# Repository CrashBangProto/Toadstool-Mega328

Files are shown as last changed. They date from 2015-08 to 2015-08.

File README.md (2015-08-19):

Toadstool Logo
#Toadstool-Mega328

**Toadstool Development Board - ATmega328P**

The Toadstool family is made up of breadboard-friendly prototyping boards that house a microcontroller, and modules called *Caps* that connect using a standard header.  The prototyping board is analagous to an Arduino/Launchpad and the Cap analagous to a shield/boosterpack.

This repository contains the schematics for the **Toadstool-Mega328** prototyping board, a breadboard-friendly PCB that houses the ATmega328P microcontroller (or other Atmel pin-compatible variants such as the ATmega8/48/88/168/328).

The boards were layed out using [KiCad](http://www.kicad-pcb.org) - KiCad is open source and awesome.

There are a number of other CrashBangProto respositories containing the schematics for other Toadstool boards and Caps, as well as sample code to get you up and running.

Visit the [Toadstool Webpages](http://www.crash-bang.com/projects/toadstool/) for more information on the project.

Toadstool Board

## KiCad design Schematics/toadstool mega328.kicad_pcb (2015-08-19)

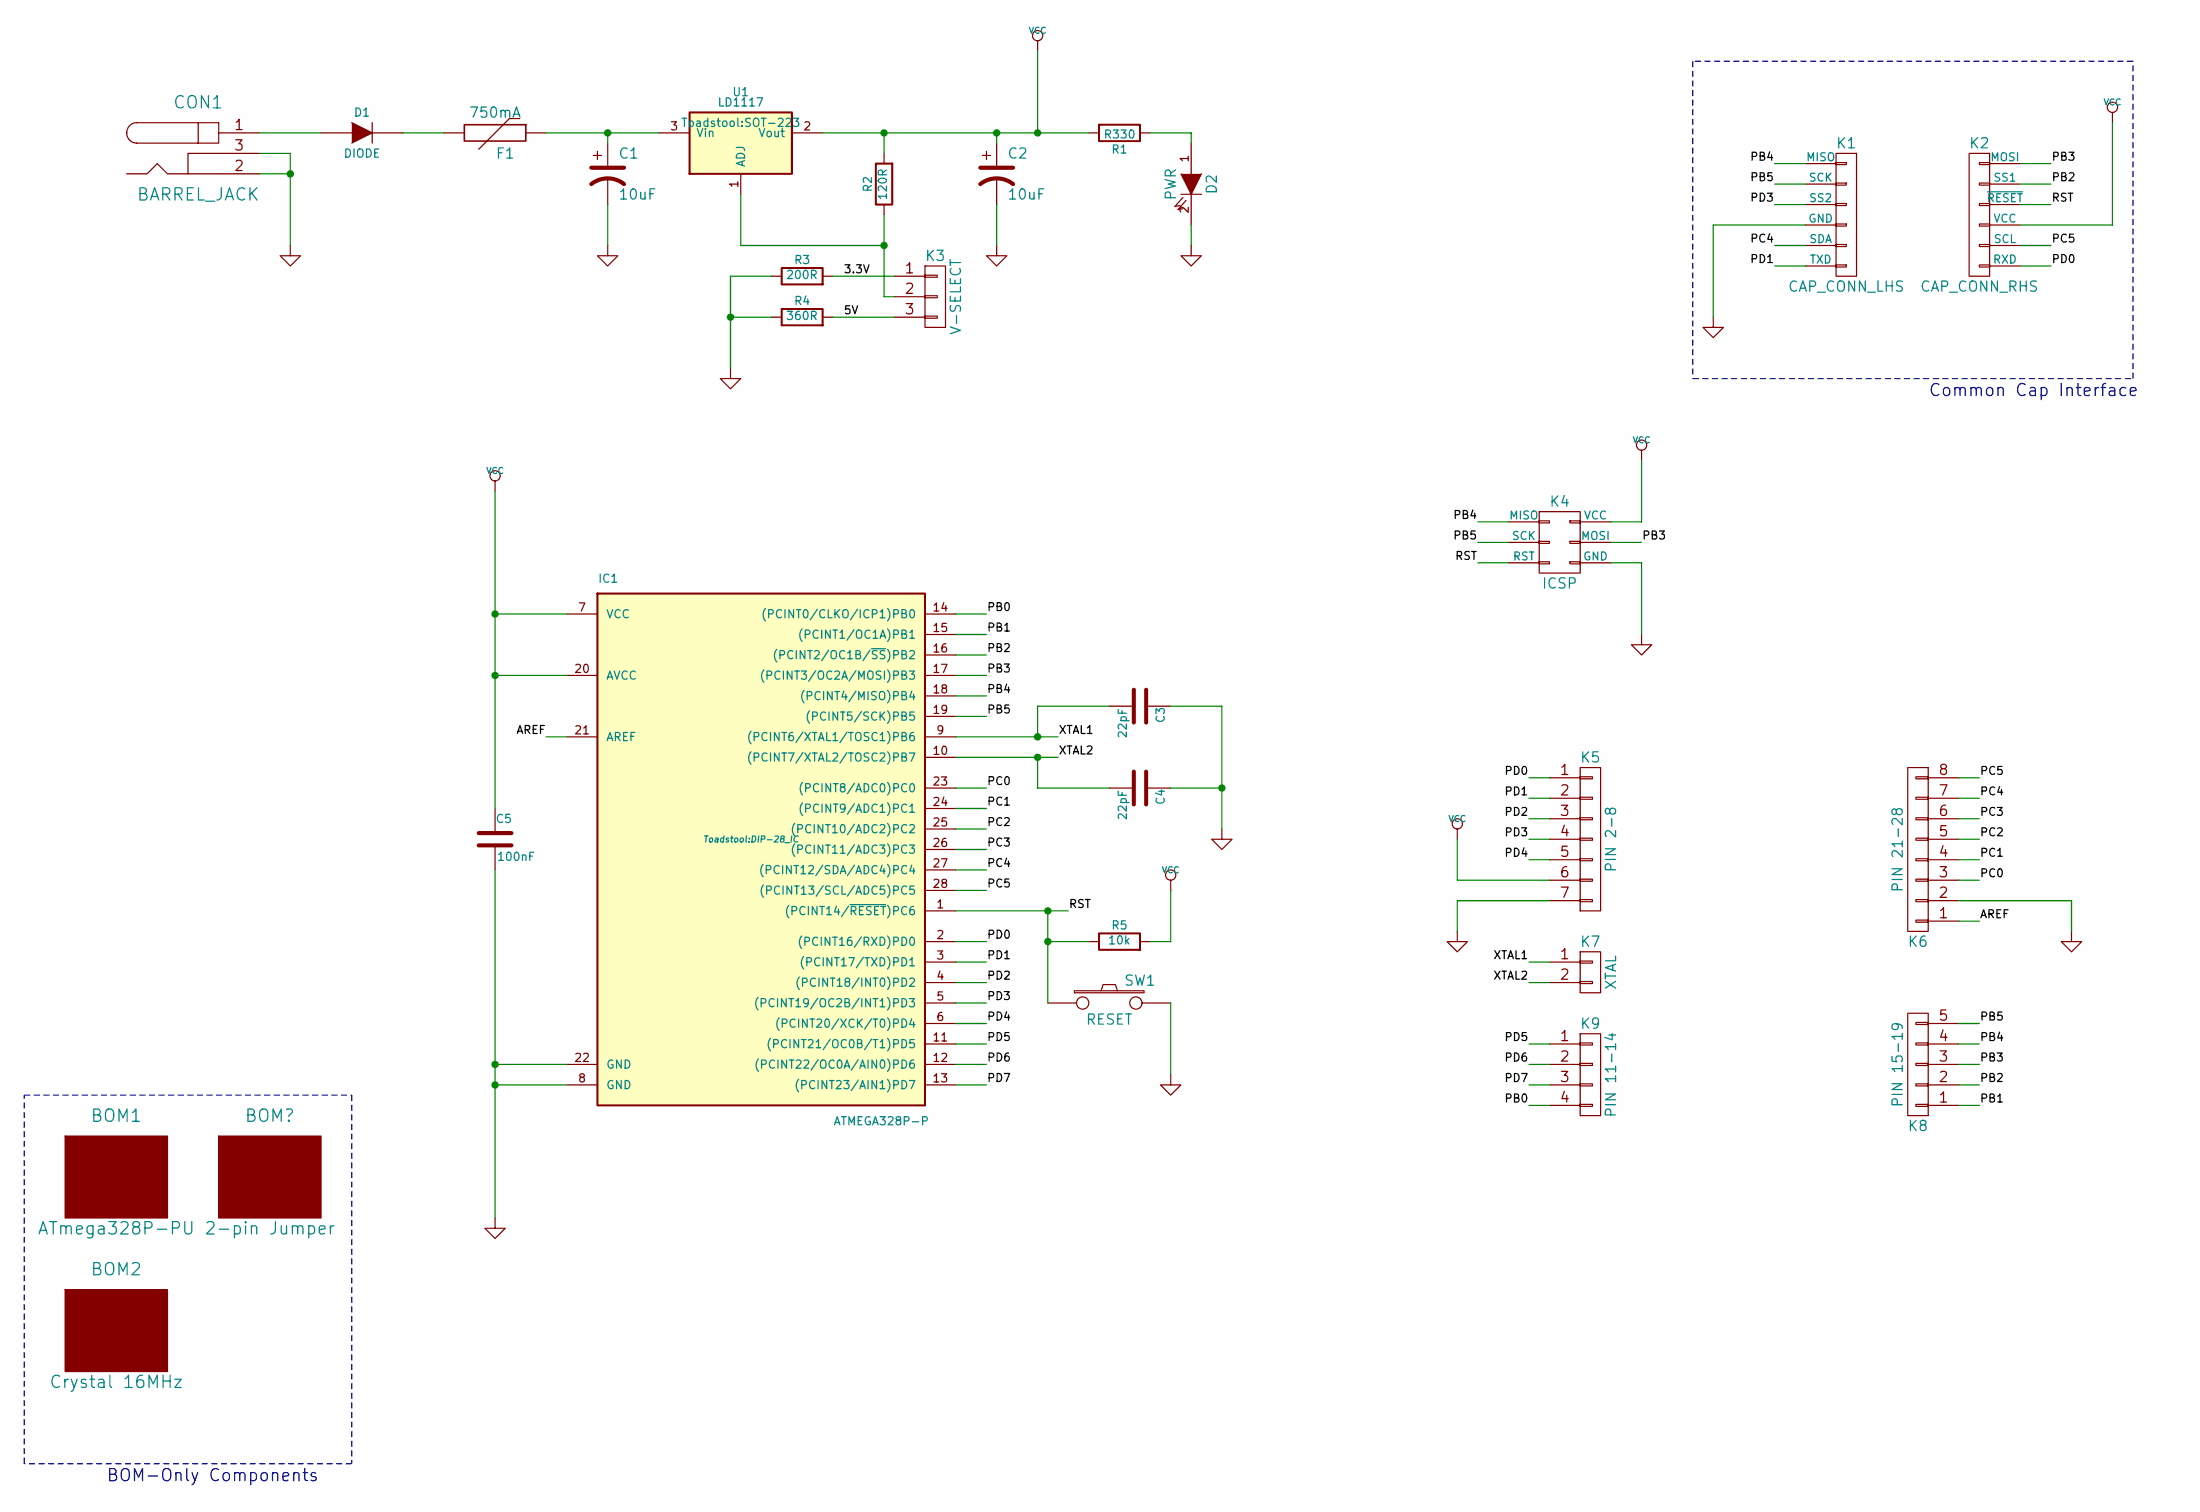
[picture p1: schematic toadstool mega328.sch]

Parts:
BOM1: ATmega328P-PU; Mfg_Part_No ATmega328P-PU
BOM2: Crystal 16MHz; Mfg_Part_No FOXSLF/160-20
C1, C2: 10uF; c_elec_4x5.3; Mfg_Part_No UWX1C100MCL1GB
C3, C4: 22pF; C_0805_HandSoldering; Mfg_Part_No C0805C220J1GACTU
C5: 100nF; C_0805_HandSoldering; Mfg_Part_No C0805C104K5RACTU
CON1: BARREL_JACK; BARREL_JACK_No_Slot; Mfg_Part_No PJ-002A
D1: DIODE; Diode_D3; Mfg_Part_No 1N5819
D2: PWR; LED-0805; Mfg_Part_No LH R974
F1: 750mA; MiniSMDPTC-4532; Mfg_Part_No MICROSMD050F-2
IC1: ATMEGA328P-P; DIP-28_IC; Mfg_Part_No A 28-LC/7-T
K1: CAP_CONN_LHS; Socket_Strip_Straight_1x06; Mfg_Part_No ESQ-106-12-G-S
K2: CAP_CONN_RHS; Socket_Strip_Straight_1x06; Mfg_Part_No ESQ-106-12-G-S
K3: V-SELECT; Pin_Header_Straight_1x03; Mfg_Part_No M20-9990345
K4: ICSP; ICSP_Header_2x03; Mfg_Part_No 30306-6002HB
K5: PIN 2-8; Pin_Header_Straight_1x07; Mfg_Part_No 61300711121
K6: PIN 21-28; Pin_Header_Straight_1x08; Mfg_Part_No 61300811121
K7: XTAL; Socket_Strip_Straight_1x02; Mfg_Part_No 310-87-102-41-001101
K8: PIN 15-19; Pin_Header_Straight_1x05; Mfg_Part_No 61300511121
K9: PIN 11-14; Pin_Header_Straight_1x04; Mfg_Part_No 61300411121
R1: R330; R_0805_HandSoldering; Mfg_Part_No CRG0805F330R
R2: 120R; R_0805_HandSoldering; Mfg_Part_No ERJ-6ENF1200V
R3: 200R; R_0805_HandSoldering; Mfg_Part_No ERJ-6ENF2000V
R4: 360R; R_0805_HandSoldering; Mfg_Part_No ERJ-6ENF3600V
R5: 10k; R_0805_HandSoldering; Mfg_Part_No CRG0805F10K
SW1: RESET; Switch_SMT_Alps_SKQGAxE010; Mfg_Part_No KSEM31G LFS
U1: LD1117; SOT-223; Mfg_Part_No LD1117STR

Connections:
/3.3V: K3.1, R3.2
/5V: K3.3, R4.2
/AREF: IC1.21 (AREF), K6.1
/PB0: IC1.14 ((PCINT0/CLKO/ICP1)PB0), K9.4
/PB1: IC1.15 ((PCINT1/OC1A)PB1), K8.1
/PB2: IC1.16 ((PCINT2/OC1B/~SS~)PB2), K2.2 (SS1), K8.2
/PB3: IC1.17 ((PCINT3/OC2A/MOSI)PB3), K2.1 (MOSI), K4.4 (MOSI), K8.3
/PB4: IC1.18 ((PCINT4/MISO)PB4), K1.1 (MISO), K4.1 (MISO), K8.4
/PB5: IC1.19 ((PCINT5/SCK)PB5), K1.2 (SCK), K4.3 (SCK), K8.5
/PC0: IC1.23 ((PCINT8/ADC0)PC0), K6.3
/PC1: IC1.24 ((PCINT9/ADC1)PC1), K6.4
/PC2: IC1.25 ((PCINT10/ADC2)PC2), K6.5
/PC3: IC1.26 ((PCINT11/ADC3)PC3), K6.6
/PC4: IC1.27 ((PCINT12/SDA/ADC4)PC4), K1.5 (SDA), K6.7
/PC5: IC1.28 ((PCINT13/SCL/ADC5)PC5), K2.5 (SCL), K6.8
/PD0: IC1.2 ((PCINT16/RXD)PD0), K2.6 (RXD), K5.1
/PD1: IC1.3 ((PCINT17/TXD)PD1), K1.6 (TXD), K5.2
/PD2: IC1.4 ((PCINT18/INT0)PD2), K5.3
/PD3: IC1.5 ((PCINT19/OC2B/INT1)PD3), K1.3 (SS2), K5.4
/PD4: IC1.6 ((PCINT20/XCK/T0)PD4), K5.5
/PD5: IC1.11 ((PCINT21/OC0B/T1)PD5), K9.1
/PD6: IC1.12 ((PCINT22/OC0A/AIN0)PD6), K9.2
/PD7: IC1.13 ((PCINT23/AIN1)PD7), K9.3
/RST: IC1.1 ((PCINT14/~RESET~)PC6), K2.3 (~RESET), K4.5 (RST), R5.1, SW1.1
/XTAL1: C3.2, IC1.9 ((PCINT6/XTAL1/TOSC1)PB6), K7.1
/XTAL2: C4.2, IC1.10 ((PCINT7/XTAL2/TOSC2)PB7), K7.2
GND: C1.2, C2.2, C3.1, C4.1, C5.2, CON1.2, CON1.3, D2.2 (K), IC1.8 (GND), IC1.22 (GND), K1.4 (GND), K4.6 (GND), K5.7, K6.2, R3.1, R4.1, SW1.2
unnamed: C1.1, F1.1, U1.3 (Vin)
unnamed: CON1.1, D1.1 (A)
unnamed: D1.2 (K), F1.2
unnamed: D2.1 (A), R1.1
unnamed: K3.2, R2.1, U1.1 (ADJ)
VCC: C2.1, C5.1, IC1.7 (VCC), IC1.20 (AVCC), K2.4 (VCC), K4.2 (VCC), K5.6, R1.2, R2.2, R5.2, U1.2 (Vout)

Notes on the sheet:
Common Cap Interface
BOM-Only Components

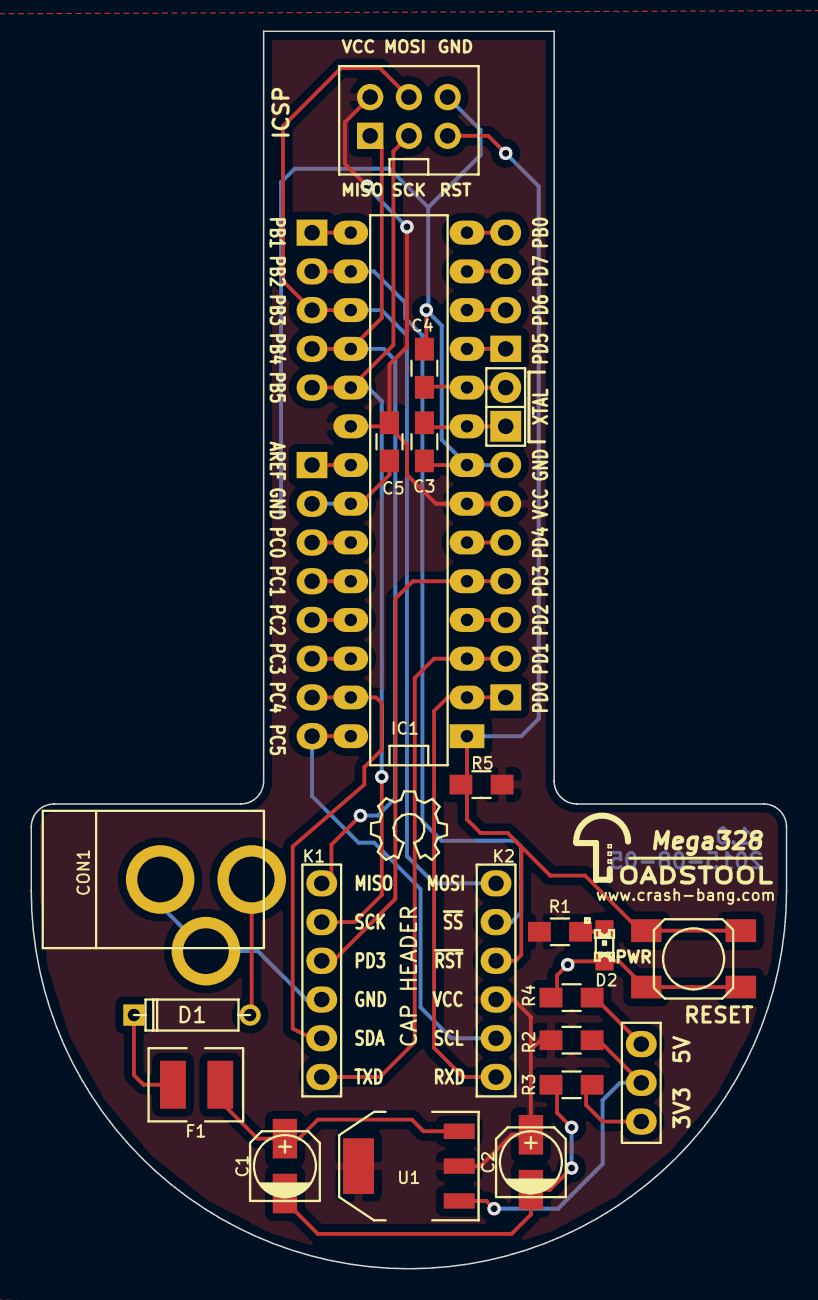
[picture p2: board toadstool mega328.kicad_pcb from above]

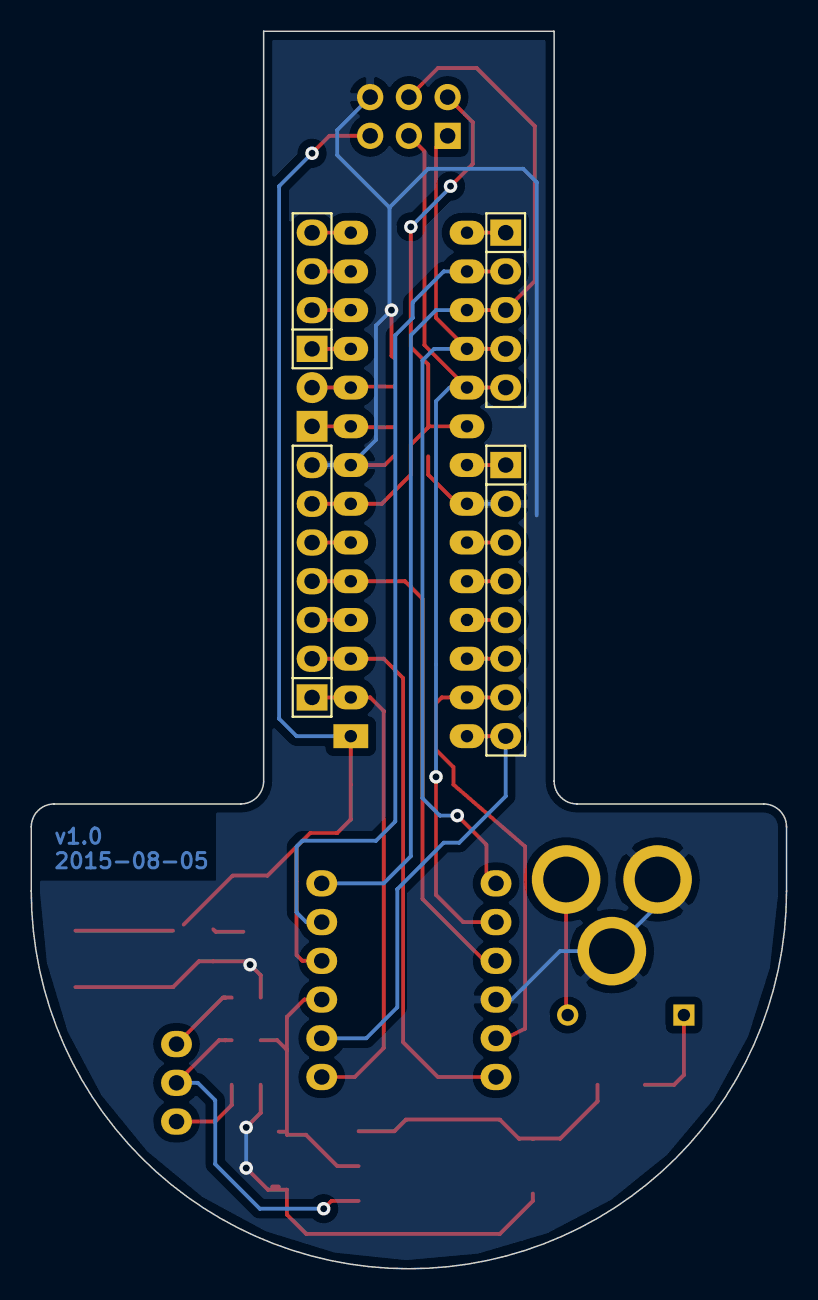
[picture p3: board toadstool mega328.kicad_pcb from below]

Board: 2 copper layers, 49.5 x 81.2 mm, 27 parts (4 on the bottom side), 33 nets.

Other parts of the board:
Toadstool_Logo: LOGO**; Toadstool_Logo

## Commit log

2015-01-01 Initial Commit - v0.1
    Version 0.1
    Original PCB layouts sent to PCB fab for prototyping round 1
    [toadstool mega328.kicad_pcb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]
2015-02-17 Cosmetic
    Rounding of board corners
    Change logo
    [toadstool mega328.kicad_pcb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]
2015-03-04 Components Changed
    Updated Power Jack and Reset button with 3D models.
    Minor changes to silkscreen
    [toadstool mega328.kicad_pcb, toadstool mega328.sch]
2015-03-24 Version 0.2 - Updates from v0.1 prototype
    Final changes from v0.1 prototype:
    - Add aluminium caps
    - Silkscreen cosmetics
    [toadstool mega328.kicad_pcb, toadstool mega328.sch]
2015-03-24 Delete toadstool mega328.kicad_pcb-bak
    Delete backup
2015-03-31 Cap Header
    Widening of Cap Header
    [toadstool mega328.kicad_pcb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]
2015-05-15 Final Prototype Commit
    [toadstool mega328.kicad_pcb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]
2015-08-19 Cosmetic Changes to Silkscreen
    Cosmetic Changes to Silkscreen
    [toadstool mega328.kicad_pcb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]
